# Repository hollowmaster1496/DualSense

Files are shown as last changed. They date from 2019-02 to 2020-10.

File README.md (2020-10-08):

# DualSense

### Introduction

The objective of this project is to provide an alternative navigation solution for visually-impaired people. The system detects objects using proximity sensors and provides feedback through vibrations so that users can safely navigate in the presence of obstacles. Different feedback schemes are used to distinguish obstacles by proximity. 

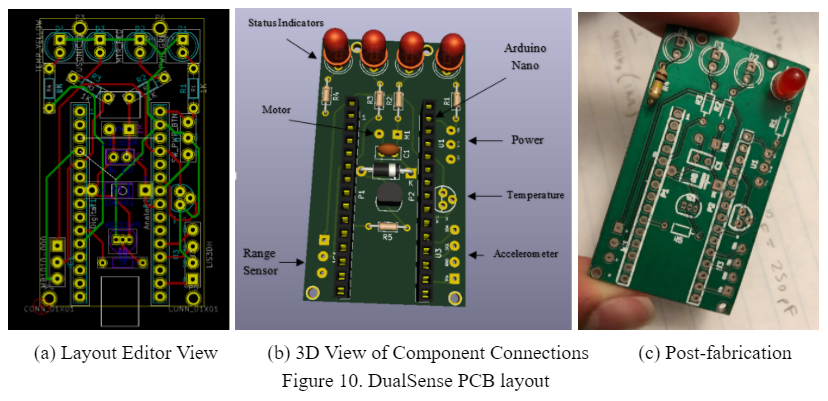
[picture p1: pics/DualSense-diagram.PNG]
DualSense PCB


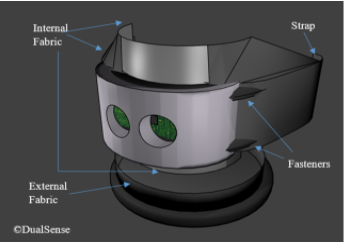
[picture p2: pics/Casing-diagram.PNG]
DualSense Encasing


Group (2019.047): Haseeb Syed, Ahsan Shahid, Jerry Zhang, Zain Jafri

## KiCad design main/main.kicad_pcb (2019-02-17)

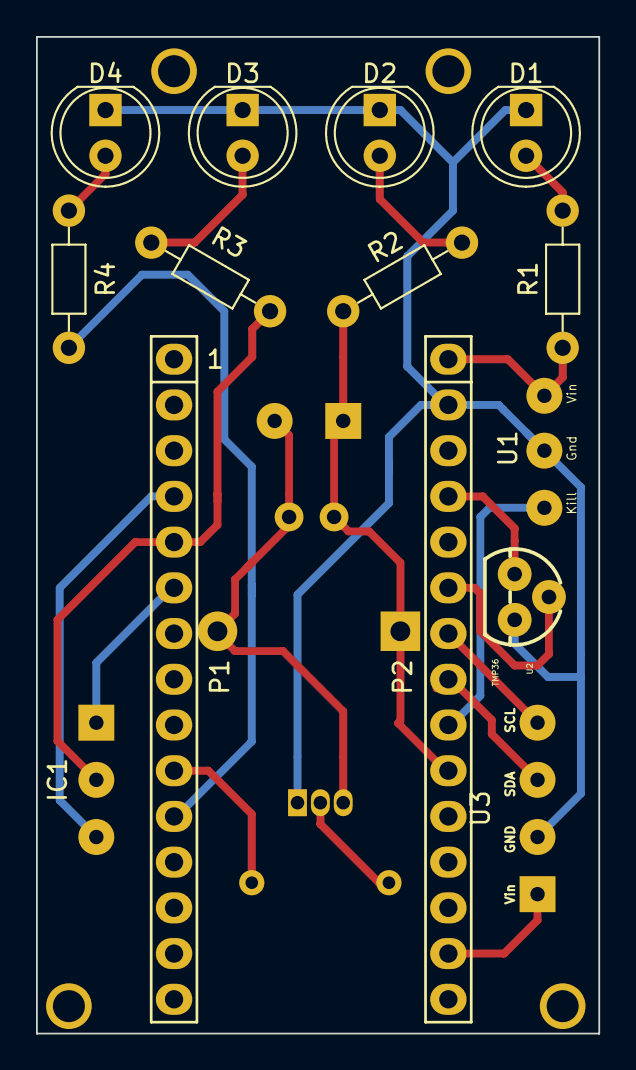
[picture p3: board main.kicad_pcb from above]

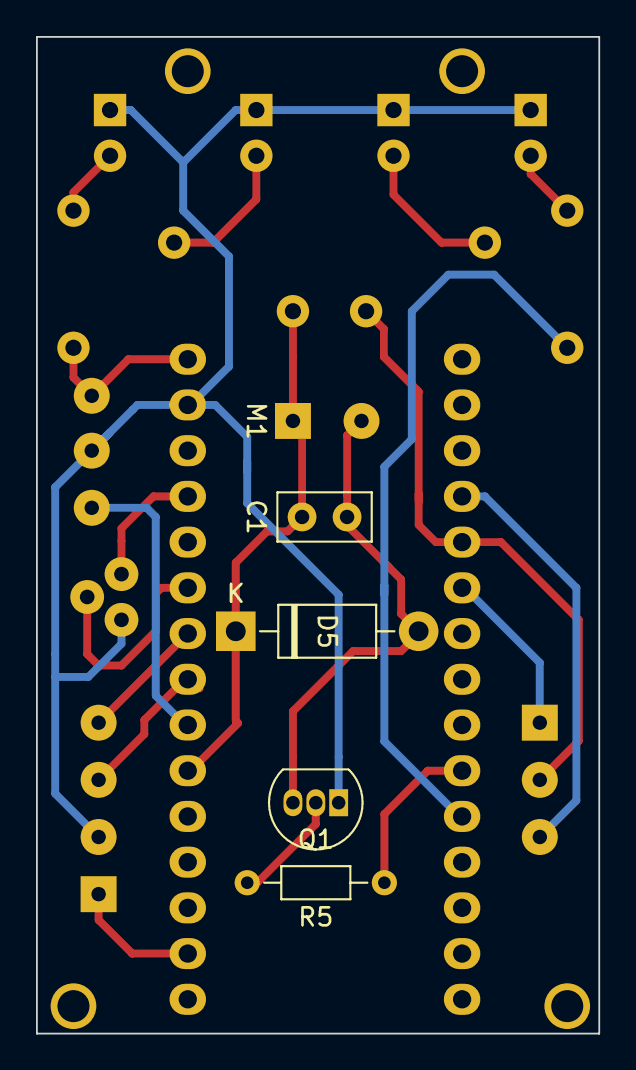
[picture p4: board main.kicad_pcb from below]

Board: 2 copper layers, 31.2 x 55.4 mm, 23 parts (5 on the bottom side), 20 nets.

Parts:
C1: 0.1 uF; C_Disc_D5.0mm_W2.5mm_P2.50mm
D1: PWR_GREEN; LED_D5.0mm
D2: MTR_RED; LED_D5.0mm
D3: USONIC_BLUE; LED_D5.0mm
D4: TEMP_YELLOW; LED_D5.0mm
D5: 1N4001; D_DO-41_SOD81_P10.16mm_Horizontal
IC1: MB1010-000; SolderWirePad_1x03_P3.175mm_Drill0.8mm
M1: Motor_DC; SolderWirePad_1x02_P3.81mm_Drill0.8mm
P1: Digital; Socket_Strip_Arduino_1x15
P2: Analog; Socket_Strip_Arduino_1x15
P3, P4, P5, P6: CONN_01X01; 1pin_Nano
Q1: PN2222A; TO-92_Inline
R1, R2, R3, R4, R5: 1K; R_Axial_DIN0204_L3.6mm_D1.6mm_P7.62mm_Horizontal
U1: SW_PWR_BTN; SolderWirePad_3holes_1x03_P3.175mm_Drill0.8mm
U2: TMP36; TO-92
U3: LIS3DH; SolderWirePad_1x04_P3.175mm_Drill0.8mm_LIS3DH_I2C

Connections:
+3V3: P2.14, U3.14
+5V: P2.4, U2.1
/2: IC1.2, P1.5, R3.1
/3(**): IC1.6, P1.6
/7: P1.10, R5.1
/8: P1.11, R4.1
/A2: C1.1, D5.1, M1.1, P2.10, R2.1
/A3: P2.9, U1.4
/A4: P2.8, U3.6
/A5: P2.7, U3.4
/A6: P2.6, U2.2
/Reset: P1.3, P2.3
/Vin: P2.1, R1.1, U1.2
GND: D1.1, D2.1, D3.1, D4.1, IC1.7, P1.4, P2.2, Q1.1, U1.3, U2.3, U3.5
unnamed: C1.2, D5.2, M1.2, Q1.3
unnamed: D1.2, R1.2
unnamed: D2.2, R2.2
unnamed: D3.2, R3.2
unnamed: D4.2, R4.2
unnamed: Q1.2, R5.2

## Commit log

2019-01-13 initial commit: Created new KiCad repository
2019-01-13 main: Added template for Arduino Nano Shield
    [main.kicad_pcb]
2019-01-13 main.sch: Added Battery Interface
    This contains a duplicate of the Arduino Nano on-board
    voltage regulator. This is specifically for the positioning
    the heat dissipation system.
    [main.sch]
2019-01-13 main.sch: Added motor interface with digital control
    The digital signal on pin D7 is used to activate the motor.
    The strength of the motor is controlled by analogue voltage signal
    from pin A7.
    [main.sch]
2019-01-18 Settings: Added project name and comments
    [main.sch]
2019-01-18 lib: Added symbols and footprints of three components:
    MB1010 - ultrasonic rangefinder sensor
    GY-521 - ITG/MPU gyroscope+accelerometer
    ARDUINO_NANO - Arduino Nano board
2019-01-18 main.pcb: Enlarged outline of board and translated mounting holes
    [main.kicad_pcb]
2019-01-20 main.sch: Added RangeFinder and Accelerometer Interfaces
    [main.sch]
2019-01-21 main.sch: Added Temperature sensor
    [main.sch]
2019-01-21 lib: Added custom library with adafruit symbols and footprints
2019-01-21 main.sch: Added adafruit push button and re-introduced battery
    [main.sch]
2019-01-25 main.sch: Added Status Indicator LEDs
    Green: Power ON
    Red: Motor ON
    Blue: Ultrasonic Sensor Active
    Yellow: Temperature HIGH
    [main.sch]
2019-01-25 main.sch: Replaced capacitor for motor interface with 0.1 uF
    [main.sch]
2019-01-25 main.sch: Modified wire lengths for compactness
    [main.sch]
2019-01-26 main.sch: Added missing footprints to symbols
    [main.sch]
2019-01-26 main.net: Updated netlist with updated footprints
2019-01-26 main.sch: Added footprints for LEDS
    [main.sch]
2019-01-26 lib: Added libraries for TMP36 and accelerometer
2019-01-26 pcb: Performed preliminary layout without traces
    [main.kicad_pcb]
2019-01-26 main.sch: Replaced temperature sensor with through-hole
    [main.sch]
2019-01-26 pcb: Updated netlist with new TMP36 sensor and re-arranged layout
    [main.kicad_pcb]
2019-01-26 pcb: Removed footprints for rangefinder sensor and push button
    These were taking up a lot of room and team decided to connect
    them using wires instead.
    [main.kicad_pcb]
2019-01-26 pcb: Performed layout of components to minimize size
    The current layout closely matches size of battery holder footprint.
    This arrangement does not yet have traces added.
    [main.kicad_pcb]
2019-01-26 pcb: Fixed mismatching endpoints of board outline
    [main.kicad_pcb]
2019-02-04 pcb: Fixed Power button wirepad footprint
    [main.kicad_pcb, main.sch]
2019-02-05 net: Replaced footprint of accelerometer with wire pads
2019-02-05 pcb: Corrected accelerometer I2C wirepad connections
    [main.kicad_pcb, main.sch]
2019-02-05 pcb: Enlarged all trace widths to 0.44mm to allow printing at
    E5 prototyping center
    [main.kicad_pcb]
2019-02-05 lib: Updated footprints for new wirepads
2019-02-05 gerbers: Generated Rev 0 Gerber files
    [main-B.Cu.gbl, main-B.SilkS.gbo, main-Edge.Cuts.gm1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]
2019-02-17 main.pcb: Reassigned pins because A7 is input ONLY
    New pin assignment:
    A6 - Temperature input
    A4 - Motor Output Control
    A5 - Kill Power
    [main.kicad_pcb, main.sch]
2019-02-17 LIS3DH: Updated footprint due to mislabled SDA and SCL
2019-02-17 main.pcb: Reassigned pins to reserve A4 and A5 for accelerometer
    [main.kicad_pcb, main.sch]
2019-02-17 main.pcb: Resolved disconnections and stray traces using Design Rules Check
    [main.kicad_pcb]
2019-02-17 main.sch: Replaced 5V line with D3 to control turn ON/OFF ultrasonic sensor
    [main.kicad_pcb, main.sch]
2019-02-17 Gerber: Generated new gerber files with latest revisions applied
    [main-B.Cu.gbl, main-B.SilkS.gbo, main-Edge.Cuts.gm1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]
